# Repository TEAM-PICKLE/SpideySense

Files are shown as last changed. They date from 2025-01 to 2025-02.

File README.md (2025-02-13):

# Spidey Sense
Project submitted to MIT RealityHack 2025. 

https://github.com/user-attachments/assets/5dcc9d4a-f0c4-42a5-9086-10be60e51206

Gain the super power of Spidey Sense!
Project Spidey Sense uses haptic motors - aka spidey sensors - to send spatial data straight to your cranium, no audio-visual cues needed. Our extra-sensory haptic headband lets you **FEEL** anything approaching from any direction.

**Problem Statement**: In XR (Extended Reality) spaces, providing spatial and directional feedback without relying on audio or visual cues presents a significant challenge. As a result, individuals with audio-visual disabilities often struggle to navigate and interact effectively within these environments. The need for a system that communicates distance and direction through alternative sensory channels is essential.

**Motivation**: The motivation behind this project stems from the concept of vehicular communication systems, which measure the proximity between vehicles and potential obstacles or collisions. This idea can be adapted for individuals with audio-visual disabilities in XR spaces. By leveraging haptic feedback as a sensory substitute, we aim to create a system that allows users to perceive spatial relationships and avoid collisions, enhancing their experience and interaction in immersive environments. 

**Objectives**: 
* Provide Haptic Sensory Feedback: To utilize haptic feedback as a mechanism to guide users' awareness towards potential obstacles and target directions. This form of tactile feedback offers a non-visual, non-auditory alternative that can communicate proximity and direction effectively.

* Demonstrate Practical Application: To develop a simple yet impactful technical demonstration that showcases the potential use of haptic feedback for spatial and directional awareness. This demonstration will highlight how the technology can be integrated into XR spaces to assist users with audio-visual disabilities.

A detailed description of components and softwares used can be found in "PROJECT SPIDEY SENSE- Hardware Components and Software Stack.pdf".

## ⚙️ Hardware Requirements
* 3D Printed Hip Hub (CAD Files provided in the "CAD Files" folder).
* [Meta Quest (tested on Meta Quest 3)](https://www.meta.com/quest/quest-3/)
* [ESP32-C3](https://www.digikey.com/en/products/detail/espressif-systems/ESP32-C3-DEVKITM-1U/15198974?gQT=2)
* [DRV8833 Dual DC Motor Driver](https://electropeak.com/drv8833-dual-motor-driver) x3
* [DC Pancake-Style Vibration Motor](https://www.digikey.com/en/products/detail/adafruit-industries-llc/1201/5353637?gQT=1) x6
* [Micro USB Breakout](https://www.sparkfun.com/sparkfun-microb-usb-breakout.html?gQT=1) x2
* [Potentiometer](https://www.digikey.com/en/products/detail/cts-electrocomponents/026TB32R103B1A1/203780)

## 🛠️ Hardware Components
### Hip Hub
Hip Hub

### Wiring Diagram - ESP32
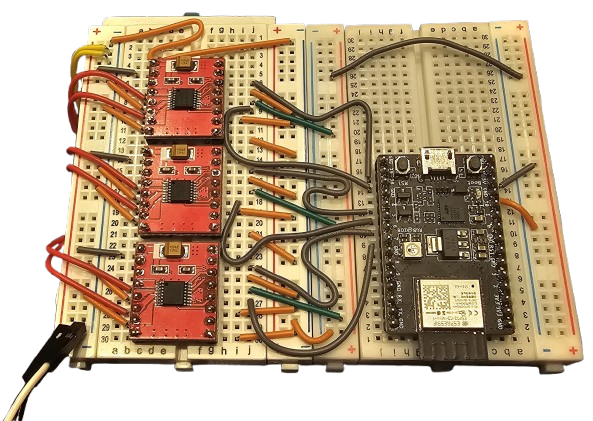
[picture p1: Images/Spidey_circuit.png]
Circuit Design


### Wiring Diagram - Hip Hub
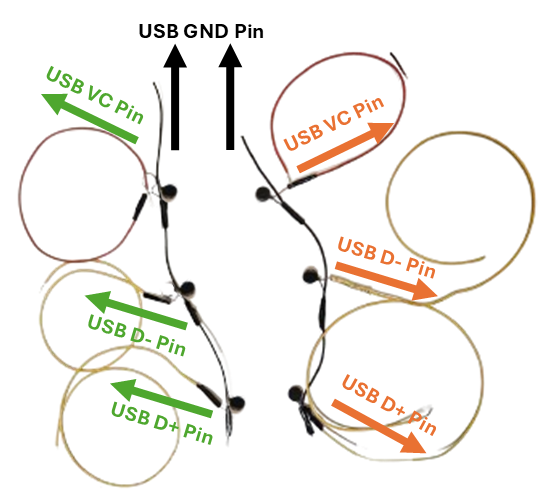
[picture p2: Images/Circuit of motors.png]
Hip Hub


## 🏷️ License
This repository is released under the MIT license.

## 🙏 Contributors
This work was done by Cheyenne Amil, Max Chen, Mahdiar Edraki, Marie Leung, Yashaswi Prasannakumar.

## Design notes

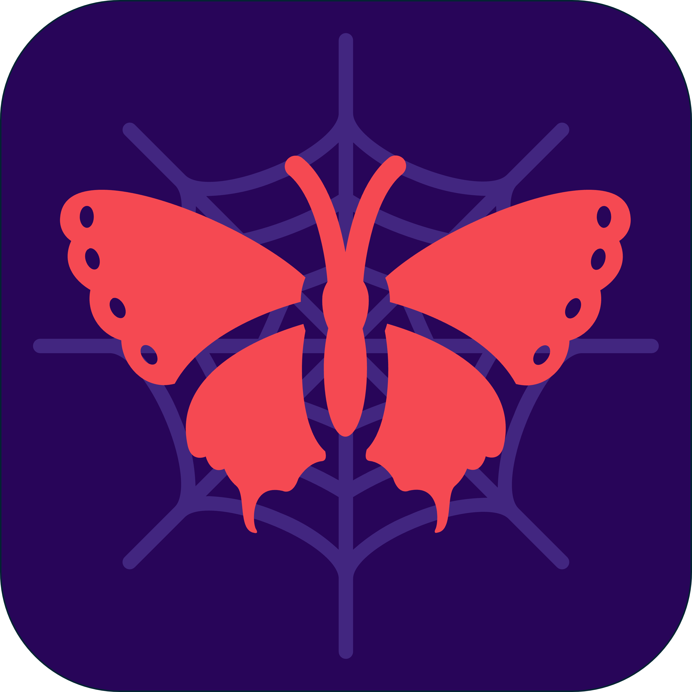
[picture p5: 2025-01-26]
Assets/Picture3.png

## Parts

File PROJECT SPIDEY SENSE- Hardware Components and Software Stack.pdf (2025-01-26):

## PROJECT SPIDEY SENSE

Team Pickle @ MIT Reality Hack 2025 - 23rd - 27th Jan, 2025
Max Chen, Mahdi Edraki, Yashaswi Prasannakumar, Cheyenne Amil, Marie Leung

### Hardware Components

### 1. ESP32

Purpose: Acts as the central microcontroller for the project, enabling communication between the vibration motors and Unity via WiFi.
Justification:
- Chosen for its powerful processing capabilities and built-in WiFi support.
- Its compatibility with Unity makes it ideal for real-time communication and control.

### 2. DRV8833 Motor Drivers (3 Units)

Purpose: Used to control and power 6 pancake vibration motors.
Justification:
- The ESP32 alone cannot safely handle the current demands of multiple motors.
- Motor drivers enable precise control of the motors through Pulse Width Modulation (PWM) signals, ensuring smooth and responsive vibration patterns.
- They allow for the use of an external 9V battery as the power source, preventing overloading and potential damage to the ESP32.

### 3. Pancake Vibrating Motors (6 Units)

Purpose: Deliver tactile feedback for the haptic headband.
Justification:
- Preferred over eccentric rotating mass (ERM) motors due to their compact design and lack of external moving parts.
- The absence of exposed oscillating masses reduces the risk of accidental injury and ensures a safer user experience.
- The pancake design provides consistent vibration feedback, enhancing the overall effectiveness of the haptic experience.

### 4. Micro USB to Breadboard Connectors (2 Units)

Purpose: Simplify the connection between the ESP32 and the custom electronics box. Justification:
- Allows for a user-friendly interface by enabling quick and hassle-free setup.
- The connectors minimize wiring complexity, reducing potential errors and making the device more robust and reliable.

1

## PROJECT SPIDEY SENSE

Team Pickle @ MIT Reality Hack 2025 - 23rd - 27th Jan, 2025
Max Chen, Mahdi Edraki, Yashaswi Prasannakumar, Cheyenne Amil, Marie Leung

### 5. Meta Quest 3

Purpose: Provides the virtual reality platform for the project, enabling immersive experiences and integrating real-time haptic feedback with virtual environments. Justification:
- Meta Quest 3 offers advanced VR capabilities with high-resolution visuals and accurate motion tracking, making it ideal for demonstrating haptic interactions.
- Its open ecosystem allows seamless integration with Unity, enabling efficient development of VR experiences synchronized with the haptic headband.

### 6. Potentiometer

Purpose: Enables manual control of the vibration intensity of the motors. Justification:
- Allows users to dynamically adjust the strength of the haptic feedback, providing a customizable and user-friendly experience.
- Ensures adaptability for different use cases and user preferences, enhancing the usability of the device.

### Summary of Design Choices

- Safety: Pancake vibrating motors were chosen to eliminate external moving parts, ensuring user safety.
- Reliability: Motor drivers offload power demands from the ESP32, enhancing system durability.
- User Convenience: Micro USB connectors were used for a plug-and-play setup, simplifying the user experience.
- Performance:
- ESP32 for real-time wireless communication and control.
- Meta Quest 3 for immersive VR integration, offering a synchronized experience between visual cues and haptic feedback.

### Software Stack:

- Technologies
- Blender
- Arduino IDE
- Unity
- Solidworks
- Free CAD
- Libraries/frameworks
- Singularity
- Meta SDK all in one

2

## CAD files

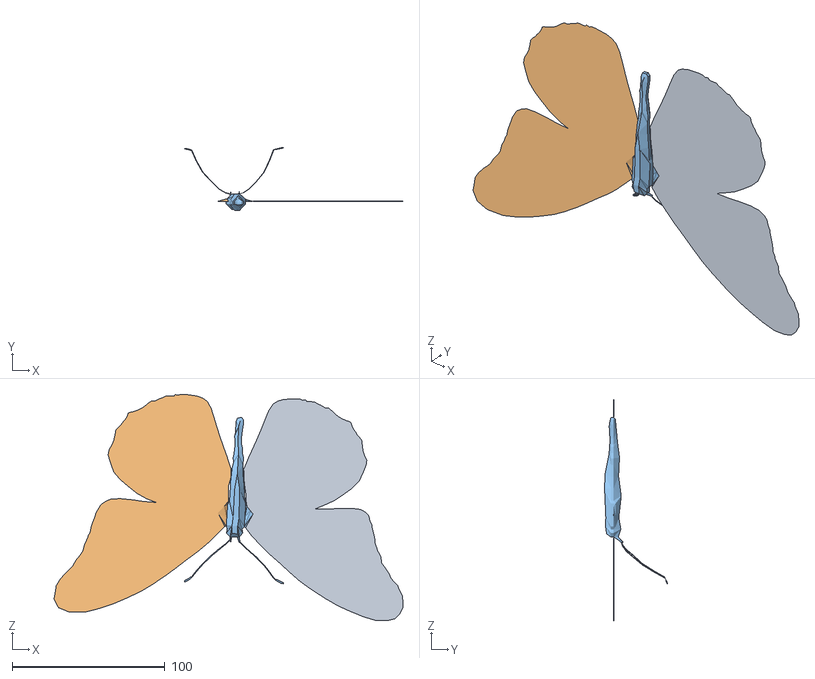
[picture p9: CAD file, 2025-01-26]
Assets/Models/_butterfly.obj
228.4 x 41.2 x 148.1
Wing_Right
Wing_Left

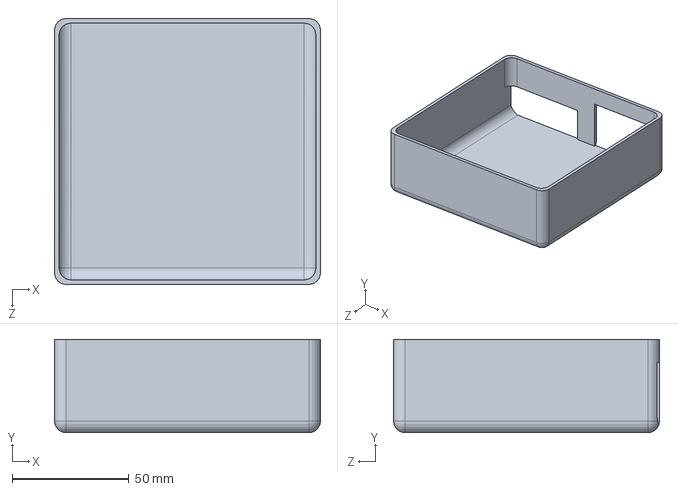
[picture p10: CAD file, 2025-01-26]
CAD Files/Hip Hub.SLDPRT
114.0 x 40.0 x 114.0 mm

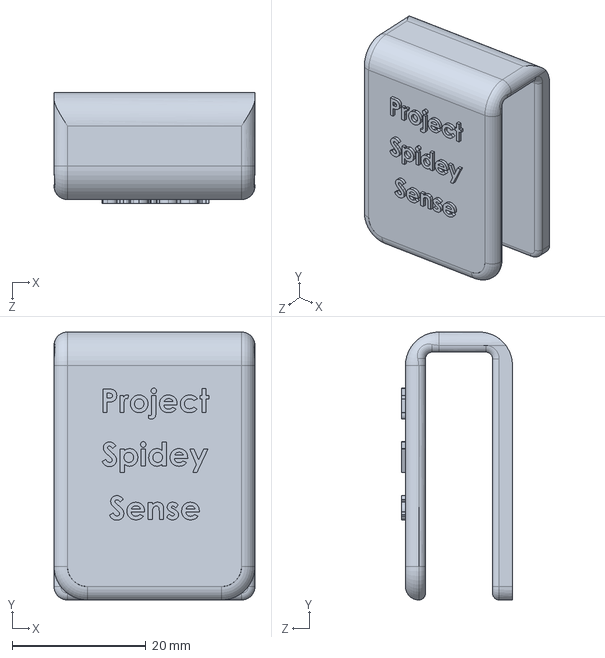
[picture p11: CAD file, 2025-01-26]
CAD Files/Belt Buckle.SLDPRT
30.0 x 40.0 x 16.6 mm

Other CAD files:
CAD Files/Belt Buckle.STL
CAD Files/Hip Hub.STL

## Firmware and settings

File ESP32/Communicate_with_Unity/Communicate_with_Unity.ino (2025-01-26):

#include <WiFi.h>

// USER DEFINED

int MotorPins[] = {5, 6, 7, 4, 19, 18}; // Array of motor pins
int potPin = 1;      // Potentiometer connected to pin 1
// Variables for filtering potentiometer value
float alpha = 0.5;                // Smoothing factor (0.0 to 1.0, smaller is smoother)
float smoothedPotValue = 0;       // Smoothed potentiometer value
int rawPotValue = 0; // Declare rawPotValue globally

// END USER DEFINED

// Declare the server here
WiFiServer server(80);  // Declare server to handle the connection

char PING[] = "PING";
int loops = 0;

int num_Motors = 6; // Calculate the length of the array
// int Intensity1[num_Motors];
int* Intensity1;  // Declare a pointer for the array
int* Scaled_Intensity1;  // Declare a pointer for the array
int Desired_Motor;  // Declare the Desired_Motor variable

// Call Setup_Wifi() from the WifiSetup.ino file
void setup() {
  Setup_Wifi(server);  // This will initialize the Wi-Fi network and start the server

  // Dynamically allocate memory for Intensity1 based on num_Motors
  Intensity1 = new int[num_Motors];
  Scaled_Intensity1 = new int[num_Motors];

  for (int i = 0; i < num_Motors; i++) {
    pinMode(MotorPins[i], OUTPUT); // Initialize each motor pin as OUTPUT
  }
  // Read the raw potentiometer value
  int rawPotValue = analogRead(potPin);
}

void loop() {
  
  // The server should be set up by now, so we can accept clients
  WiFiClient client = server.available();
  if (client) {
    Serial.println("Client connected!");
    
    // Send initial response to the client
    client.println("HTTP/1.1 200 OK");
    client.println("Content-Type: text/plain");
    client.println("Connection: close");
    client.println();
    
    while (client.connected()) {
      loops++;

      // Read the raw potentiometer value
      int rawPotValue = analogRead(potPin);
      // Apply exponential moving average for smoothing
      smoothedPotValue = alpha * rawPotValue + (1 - alpha) * smoothedPotValue;

      // Map the smoothed potentiometer value to a multiplier between 0 and 1
      float normalizedValue = smoothedPotValue / 4095.0; // Normalize to 0.0 - 1.0
      float multiplier;

      if (normalizedValue < 0.5) {
          // Map from 0.0-0.5 to 0.2-1.0
          multiplier = 0.2 + normalizedValue * 1.6; // Scale from 0.2 to 1
      } else {
          // Map from 0.5-1.0 to 1.0-11.0
          multiplier = 1.0 + (normalizedValue - 0.5) * 20; // Scale from 1.0 to 11.0
      }

      // **Check for incoming messages**
      if (client.available()) {
        String receivedMessage = client.readStringUntil('\n'); // Read until newline
        receivedMessage.trim(); // Remove any extra whitespace
        Serial.println("Received message: " + receivedMessage);

        // Check if the message length is greater than 0
        if (receivedMessage.length() > 0) {
        Desired_Motor = receivedMessage[0] - '0';  // Convert char to int

        // Check if Desired_Motor is within valid range
        if (Desired_Motor >= 0 && Desired_Motor < num_Motors) {
            Intensity1[Desired_Motor] = receivedMessage.substring(2).toInt();  // Get the substring from index 2 to the end and convert to int
            Serial.print(" | Multiplier: ");
            Serial.println(multiplier);
            // Calculate PWM value scaled by the potentiometer multiplier
            Scaled_Intensity1[Desired_Motor] = min(max(int(Intensity1[Desired_Motor] * multiplier), 0), 100); // Ensure within 0-100
            
            Serial.println("Actuating Motor " + String(Desired_Motor) + " on Pin " + String(MotorPins[Desired_Motor])+" with Scaled Intensity:"+ String(Scaled_Intensity1[Desired_Motor]));

            // Call the Run_Motor function
            Run_Motors(MotorPins[Desired_Motor], Scaled_Intensity1[Desired_Motor]);
        } else {
            // If Desired_Motor is out of bounds
            client.println("Error: Invalid motor number");
        }
        // delay(30);
    } else {
        // If message is empty or does not meet criteria
        client.println("Received: " + receivedMessage + " - it sucks!");
    }

      }
    }
    
    Serial.println("Client disconnected");

    // After the client disconnects, reset all motor intensities to zero
    for (int i = 0; i < num_Motors; i++) {
      Intensity1[i] = 0;
      Run_Motors(MotorPins[i], Intensity1[i]);  // Ensure motors are stopped
      Serial.println("Motor " + String(i) + " reset to intensity 0.");
    }

    client.stop(); // Close the connection
  }
}

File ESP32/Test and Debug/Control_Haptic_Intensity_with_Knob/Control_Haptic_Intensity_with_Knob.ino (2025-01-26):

// USER DEFINED
int MotorPins[] = {5, 6, 7, 4, 19, 18}; // Array of motor pins
int num_Motors = 6; // Number of motors
int potPin = 1;      // Potentiometer connected to pin 1

// Variables for filtering potentiometer value
float smoothedPotValue = 0;       // Smoothed potentiometer value
float alpha = 0.5;                // Smoothing factor (0.0 to 1.0, smaller is smoother)

void setup() {
  Serial.begin(115200); // Initialize serial communication for debugging

  for (int i = 0; i < num_Motors; i++) {
    pinMode(MotorPins[i], OUTPUT); // Initialize each motor pin as OUTPUT
    analogWrite(MotorPins[i], 0);  // Set initial PWM values to 0
  }
}

void loop() {
  // Read the raw potentiometer value
  int rawPotValue = analogRead(potPin);

  // Apply exponential moving average for smoothing
  smoothedPotValue = alpha * rawPotValue + (1 - alpha) * smoothedPotValue;

  // Map the smoothed potentiometer value to a multiplier between 0 and 1
  float multiplier = smoothedPotValue / 4095.0; // Scale to 0.0 - 1.0

  Serial.print(" | Multiplier: ");
  Serial.println(multiplier);

  // Fade in and out, scaling PWM values with the multiplier
  for (int i = 0; i < num_Motors; i++) {
    // Calculate PWM value scaled by the potentiometer multiplier
    int scaledPWM = min(max(int(255 * multiplier), 0), 255); // Ensure within 0-255

    Serial.print(" | Motor: "+ String(i)+" PWM: "+ String(scaledPWM));
    // Serial.println(multiplier);

    analogWrite(MotorPins[i], scaledPWM);
    delay(100); // Short delay for each motor
  }
}

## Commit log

2025-01-24 adding main scene and VR Camera
    simple scene with low poly assets, to be cleaned up
2025-01-25 Receiving motor and intensity from unity
2025-01-25 add sensor-enemy distance checking
2025-01-25 All six motors running
2025-01-26 adding butterfly animation
    [_butterfly.obj]
2025-01-26 reading multiple motors both in Arduino and through Unity Wifi communication
2025-01-26 fix twosided material for butterfly
2025-01-26 sensor MR
2025-01-26 Cleaned ESP32 Directory
2025-01-26 changed button
